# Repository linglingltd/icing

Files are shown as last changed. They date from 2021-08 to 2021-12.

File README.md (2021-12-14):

# Teststandes zur Erzeugung planarer Eisschichten

Eine detailiertere Beschreibung folgt, sobald der Teststand sauber geprüft
und dokumentiert ist.

# Lizenz

Dieses Repository ist Teil des Bachelor-Projekts im Rahmen meines Studiums.
Alle Teile können gemäß CC BY 2.0 verwendet werden.

# Messungsbeginn

Zu Beginn einer Messreihe immer eine Referenzierung des Teststands durchführen!

  * X HOME
  * X 5
  * Y HOME
  * Y 5
  * Z HOME
  * Z 5   (bzw. hoch genug, dass der Sensor nicht mit dem DUT kollidiert)

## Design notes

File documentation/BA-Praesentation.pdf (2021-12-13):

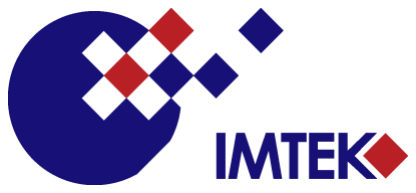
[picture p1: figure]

# Entwurf und Charakterisierung eines kapazitiven Sensors zur Detektion von Eisschichten

Bachelorthesis von Kevin R. Mader 05.11.2021
Institut für Mikrosystemtechnik - IMTEK Albert-Ludwigs-Universität Freiburg

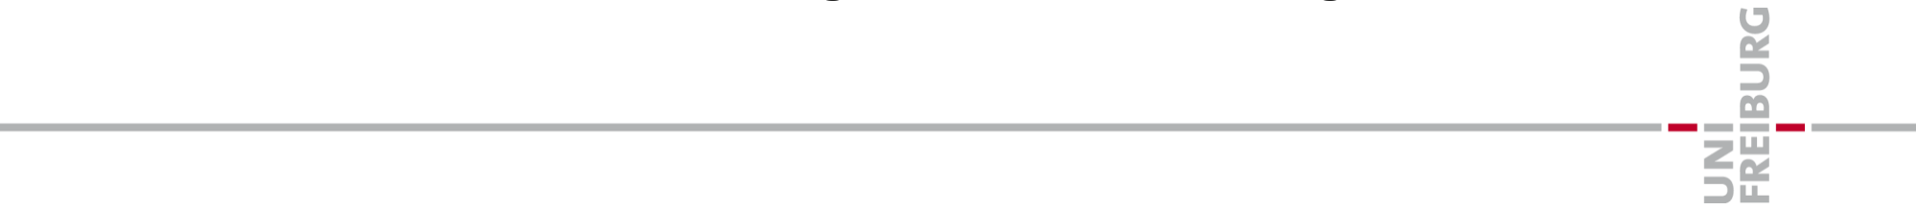
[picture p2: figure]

05.11.2021 | Kevin R. Mader

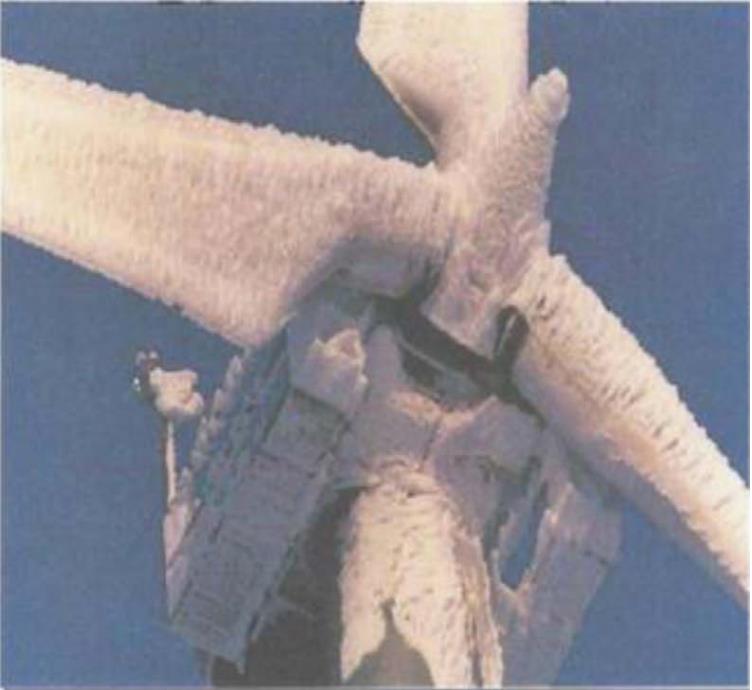
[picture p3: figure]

- 2 -

## Motivation

- Senkung der Effizienz
- Erhöhte mechanische Belastung der Windkraftanlage
- Eiswurf: Gefahr für Mensch, Tier und Gebäude
- Ab kritischer Eisschicht muss die Anlage abgeschaltet werden

(Fakoerde et al)

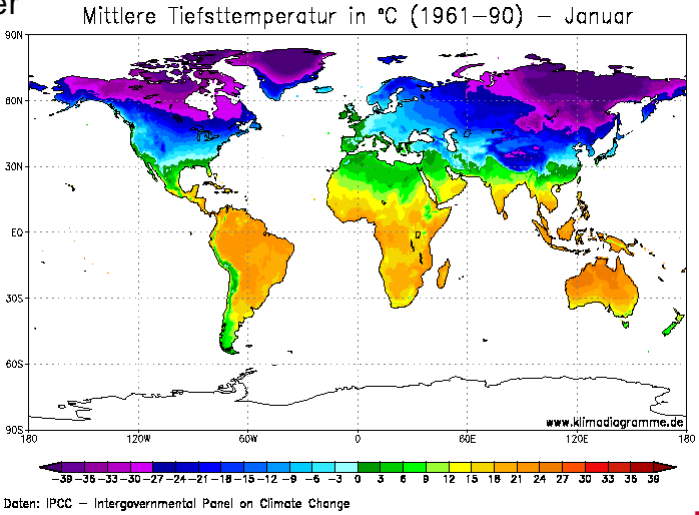
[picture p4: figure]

- 3 -

## Motivation

- Elektrische Energie sollte nah beim Verbraucher generiert werden
- Im Norden starke Winde, aber Vereisungsproblematik
- Vereisung bringt Einbußen der Energiegewinnung von
bis zu 50 % des Jahres-ertrags

## Vereisungsarten

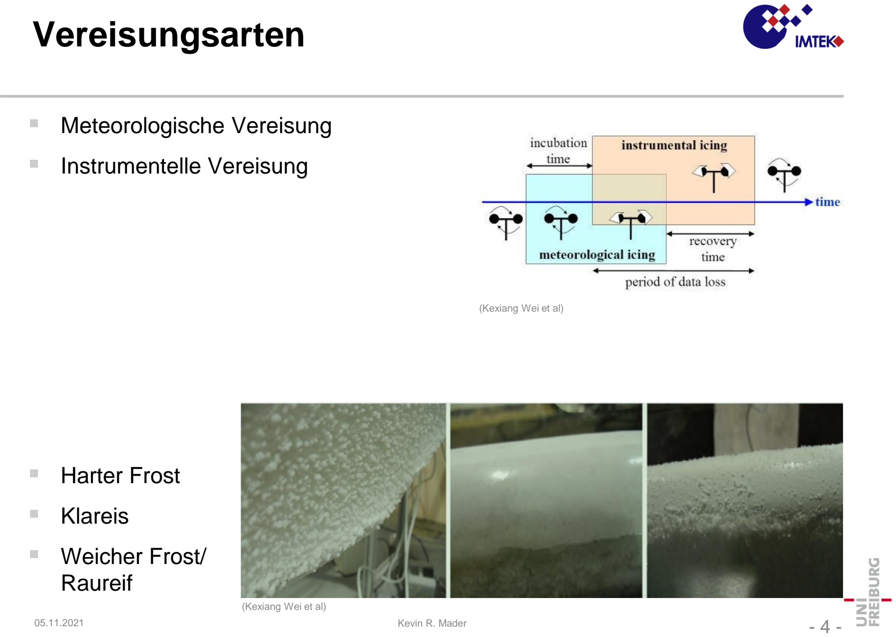
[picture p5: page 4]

- 4 -
- Meteorologische Vereisung
- Instrumentelle Vereisung
- Harter Frost
- Klareis
- Weicher Frost/
Raureif

(Kexiang Wei et al)

(Kexiang Wei et al)

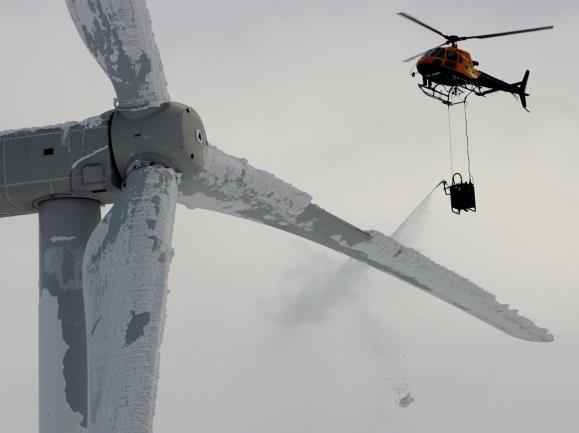
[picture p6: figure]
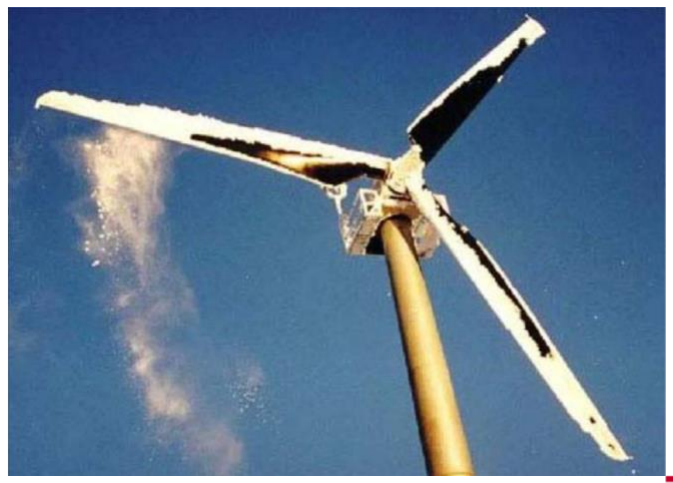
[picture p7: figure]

- 5 -

## Enteisungsmethoden

- Besprühen von Windkraftanlagen mit warmem Wasser
- Beheizen mit Verlustwärme aus der Gondel
- Energieverlust beträgt etwa 120 kW für eine 2.0 MW Windkraftanlage ab 50% Auslastung
- Aktives Beheizen mit Heizelementen
- Schwarze Rotorblätter
- Lotus-Effekt

(Fakoerde et al)

(Energiforsk)

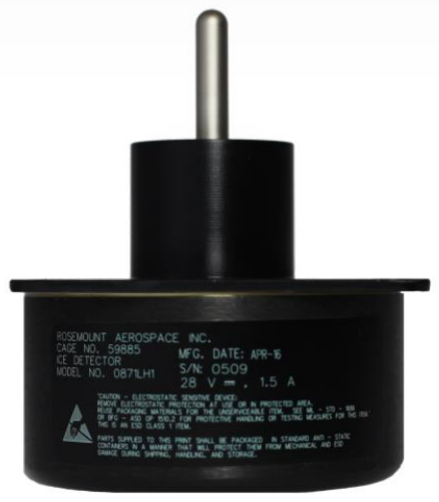
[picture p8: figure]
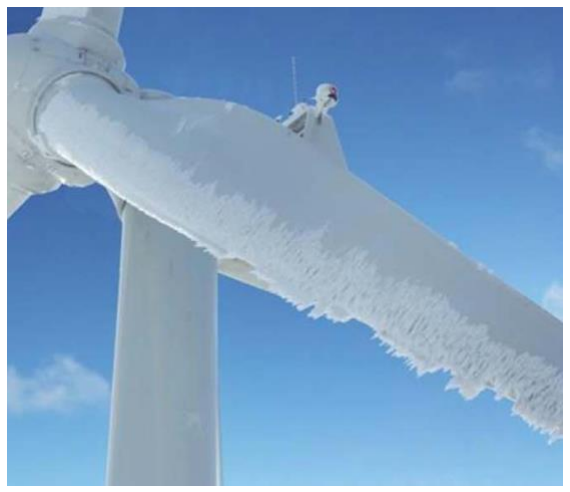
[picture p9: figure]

- 6 -

## Eisdetektion

- Vibrationsanalyse
- Windstärke und Leistungsausgabe
- Kapazitive Detektion
- Auf der Gondel
- Am Rotorblatt

(Fakoerde et al)

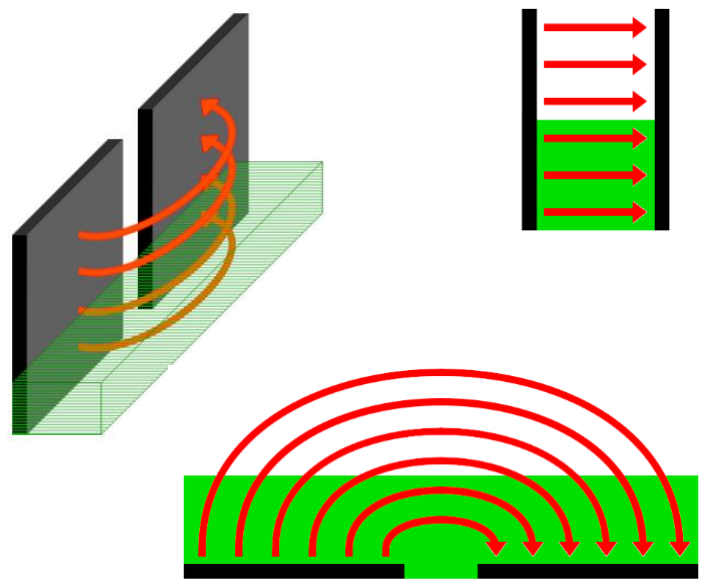
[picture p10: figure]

- 7 -

## Kapazitive Sensoren

- Plattenkondensator:
- Große Fläche b ⋅ t zueinander
- Gerade Feldlinien zwischen den Platten
- Kapazität gegeben durch C =

b⋅t
d

⋅ εr

⋅ ε0

- Lineares Signal über steigenden Füllstand
- Vertikaler koplanarer Kondensator
- Geringe Fläche b ⋅ t
- Überwiegend Streufelder
- Lineares Signal über steigenden Füllstand
- Horizontaler koplanarer Kondensator
- Mit steigendem Füllstand tritt Sättigung ein
Material | Relative Permittivität εr
Vakuum | 1,0
Luft | 1,000576 (0 °C, 105 Pa)
| 1,05404 (0 °C, 107 Pa)
Wasser | 87,9 (0 °C)
| 80,2 (20 °C)
Eis | 100 (– 20 °C, f = 50 Hz)
| 3,2 (– 20 °C, f > 100 kHz)
FR-4 | 3,2 … 4,7

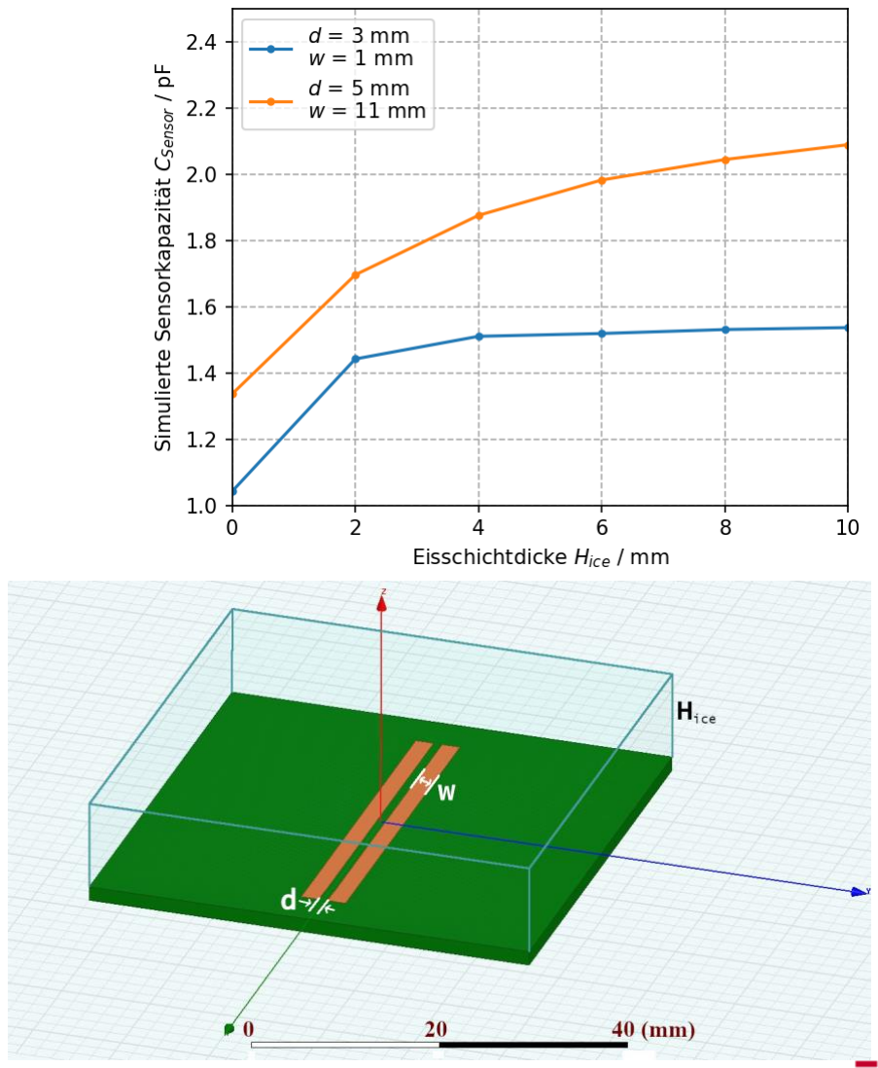
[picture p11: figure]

- 8 -

## Simulation der Sensor-Elektroden

- Simulation mit Leiterbahnbreiten und –
abständen {1 mm, 3 mm, 5 mm, 7 mm, 9 mm, 11 mm}
- Elektroden auf FR-4 (εr = 4,4)
- Umgeben von Vakuum (εr = 1)
- Auftrag mit Eis (εr = 3,2)

## Entworfener Prototyp

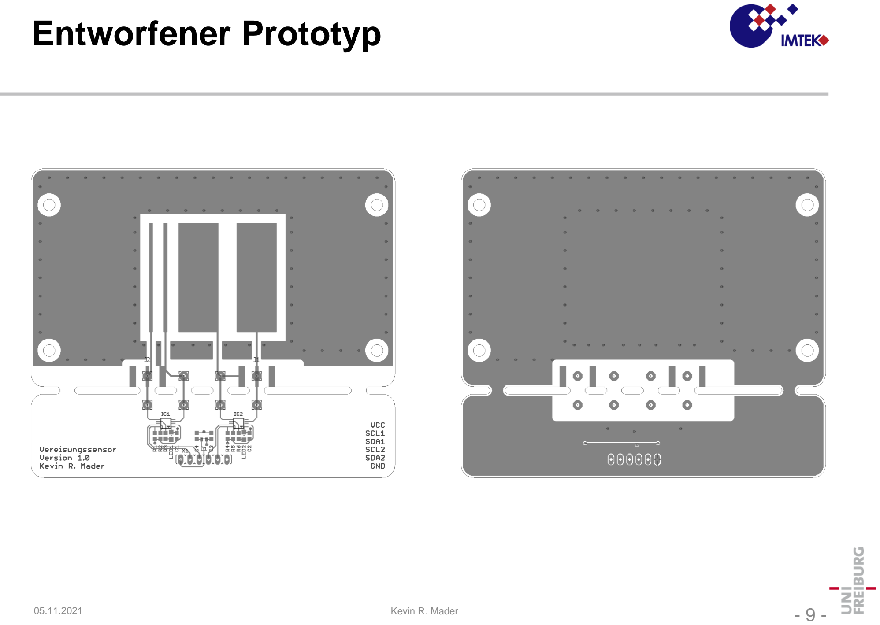
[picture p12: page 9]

- 9 -

## Messaufbau

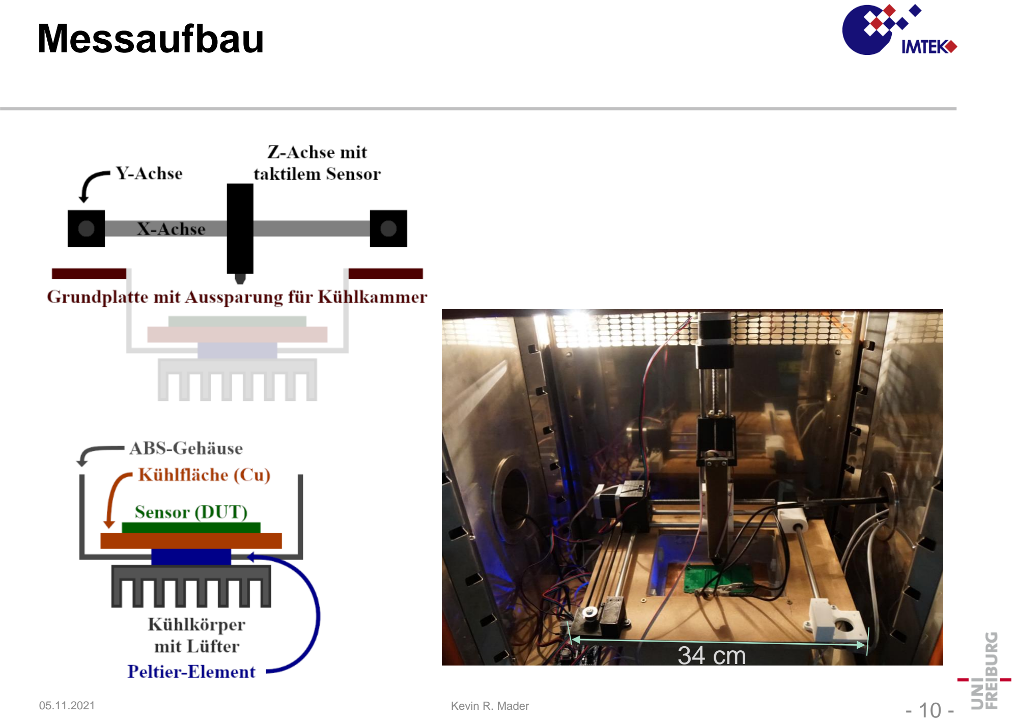
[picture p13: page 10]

- 10 -

34 cm

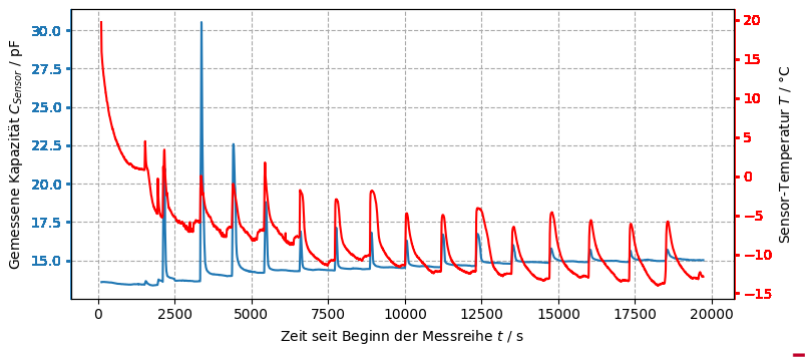
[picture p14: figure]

- 11 -

## Messdurchführung

1. Wasser aufsprühen
2. Einschwingen
3. Höhenvermessung
4. Kapazitätsmessung

- 12 -

## Datenaufzeichnung

Zusammenführen der Messwerte am Computer mit Live-Visualisierung:
- Speicherung:
- Netzwerkanalysator-Messwerte
- Sensortemperatur
- Zeitpunkt in der Messreihe
- Höhenprofile
- Live-Anzeige:
- Durchschn. Sensorkapazität
- Sensortemperatur
- Zeitpunkt in der Messreihe

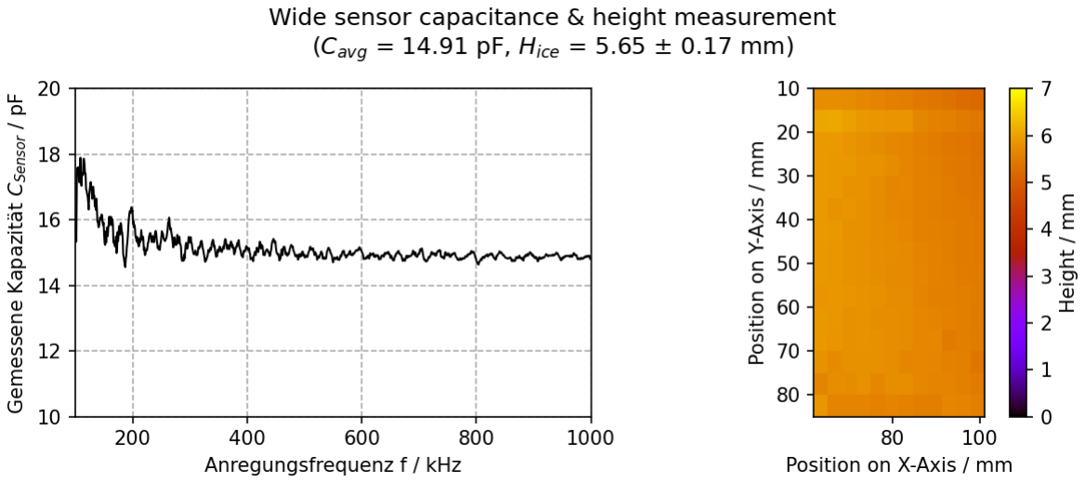
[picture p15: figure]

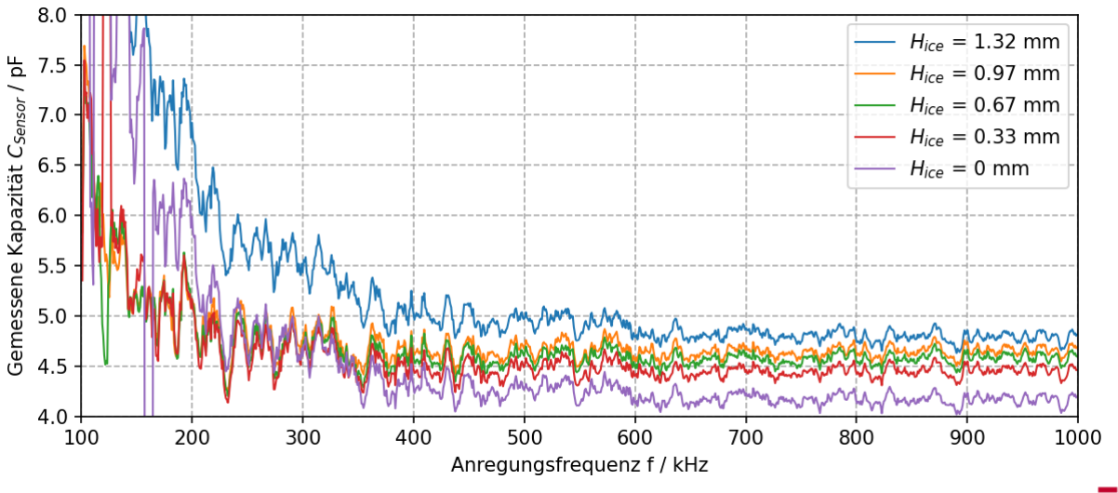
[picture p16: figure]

- 13 -

## Frequenzverhalten des Sensors

- Sinkende Kapazität mit steigender Frequenz
- Stärkeres Rauschen im unteren Frequenzbereich durch Messdauer
- Kapazitätswert aus Mittelwert der Werte zwischen 400 kHz und 1 MHz

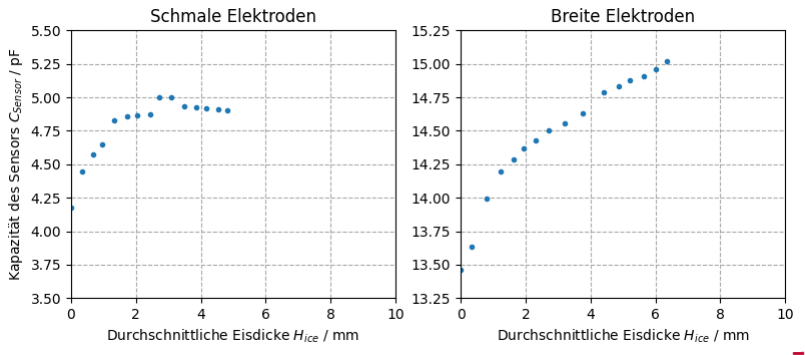
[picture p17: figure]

- 14 -

## Sensorverhalten über Eisschichtdicke

- Erhöhte Grundkapazität durch Anschluss des Netzwerkanalysators
- Schmale Elektrode in Sättigung nach 1 mm Eis

## Vergleich von Messwerten zu Simulation

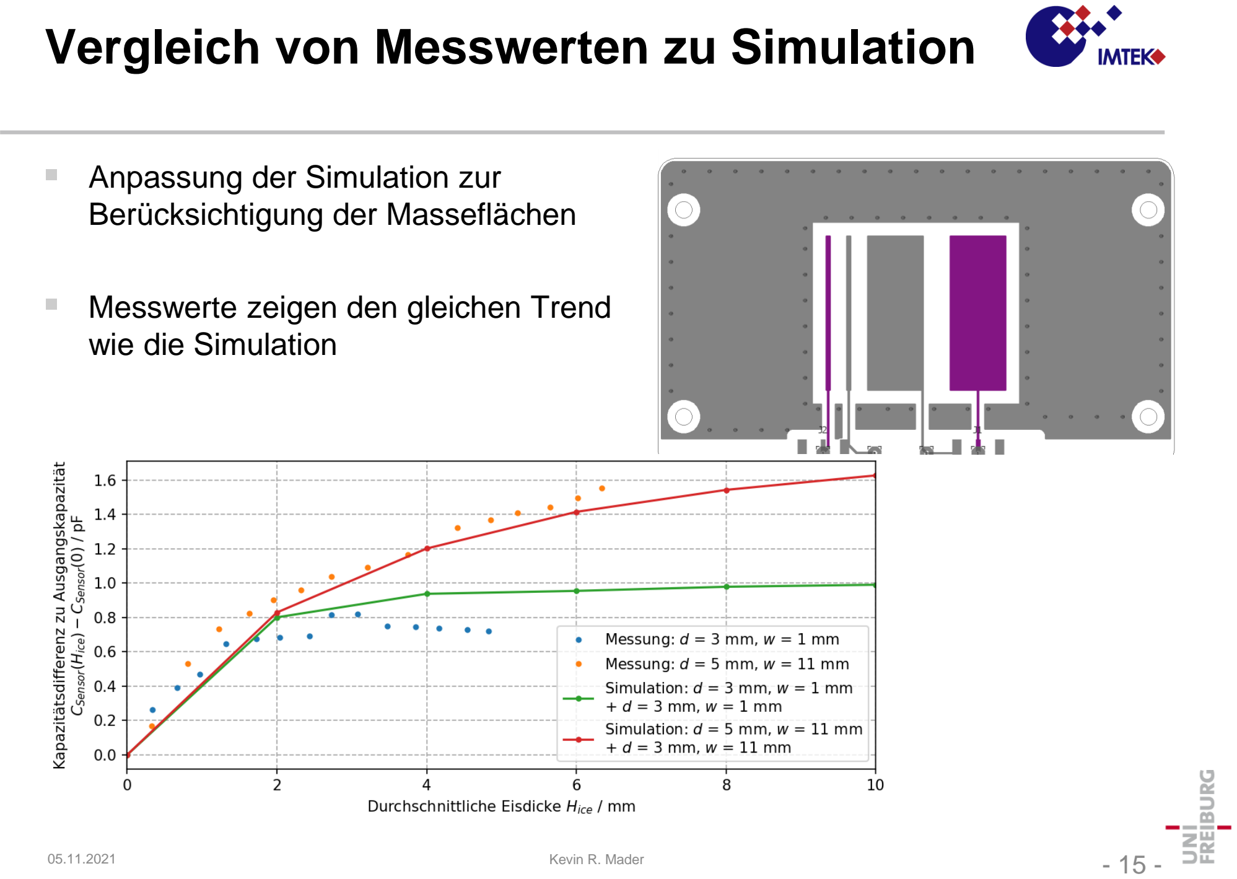
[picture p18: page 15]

- 15 -
- Anpassung der Simulation zur Berücksichtigung der Masseflächen
- Messwerte zeigen den gleichen Trend wie die Simulation

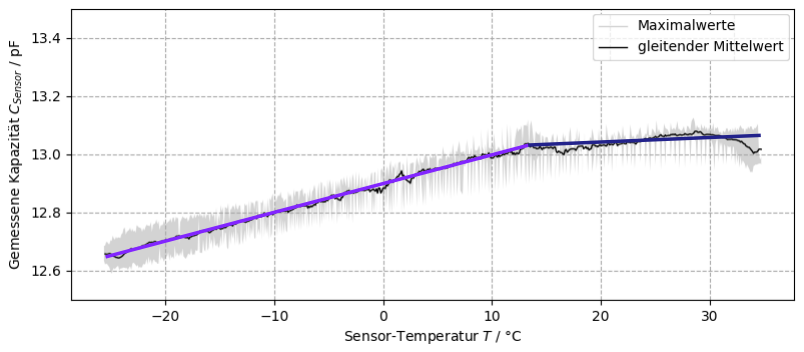
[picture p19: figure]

- 16 -

## Temperaturverhalten des Sensors

- Messung des Sensors im Klimaschrank, Zyklen zwischen −25 °C und +35 °C
- Umgebungstemperatur im Labor θAmbient = 23 °C
- relative Luftfeuchte RH = 50 %
- entspricht RH = 100 % bei θ = 13 °C

- 17 -

## Zusammenfassung

- Die Elektrodenpaare zeigen eine Empfindlichkeit für kleine Eisschichten < 1 mm von

ΔC

ΔHice

= 0.5

pF
mm

für die kleinen Elektroden und ΔC

ΔHice

= 0.7

pF
mm

für
die großen.
- Bei Eisschichten über 2 mm sind die kleinen Elektroden gesättigt, während die großen Elektroden auch hier noch eine Empfindlichkeit um ΔC

ΔHice

= 0.1

pF
mm
zeigen.

- 18 -

## Aussicht

- Messung des Temperaturverhaltens unter kontrollierter Luftfeuchte
- Erweiterung des Teststands um Temperaturregelung
- Detailliertere Charakterisierung des Verhaltens bei Eisbildung und versch. Temperaturen
- Produktion des Sensors auf dünnem, flexiblen Leiterplattenmaterial

- 19 -

## Quellen

- (Fakoerde et al) doi: 10.1016/j.rser.2016.06.080 Ice protection systems for wind turbines in cold climate: characteristics, comparisons and analysis
- (Energiforsk)
Airborne de-icing solutions for wind turbines REPORT 2016:300
- (George Xydis et al) doi: 10.3390/challe6020188
Wind turbine waste heat recovery—A short-term heat loss forecasting approach
- (Kexiang Wei et al) doi: 10.1002/we.2427
A review on ice detection technology and ice elimination technology for wind turbine

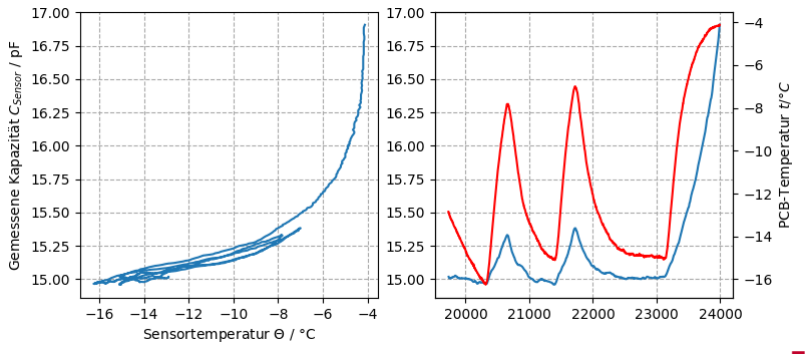
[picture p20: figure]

- 20 -

## Backup #1: Temperaturverhalten mit Eis

- Temperatur erreicht durch Ein- und Auschalten des Peltier-Elements
- Anschmelzen der oberen Eisschicht

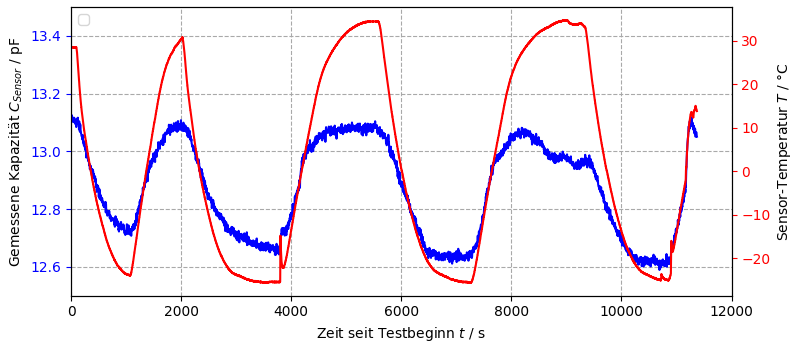
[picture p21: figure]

- 21 -

## Backup #2: Temperaturverhalten ohne Eis

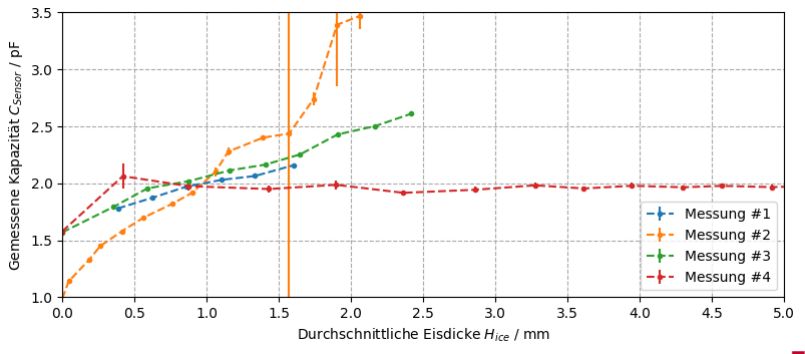
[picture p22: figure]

- 22 -

## Backup #3: LCR-Messungen

- Messung 2: Signifikante Veränderung durch verschieben der Messleitungen
- Messung 1&3: Eisbildung an den Klemmen des LCR-Meters
- Messung 4: Entfernung von Feuchtigkeit und Eis von den Klemmen

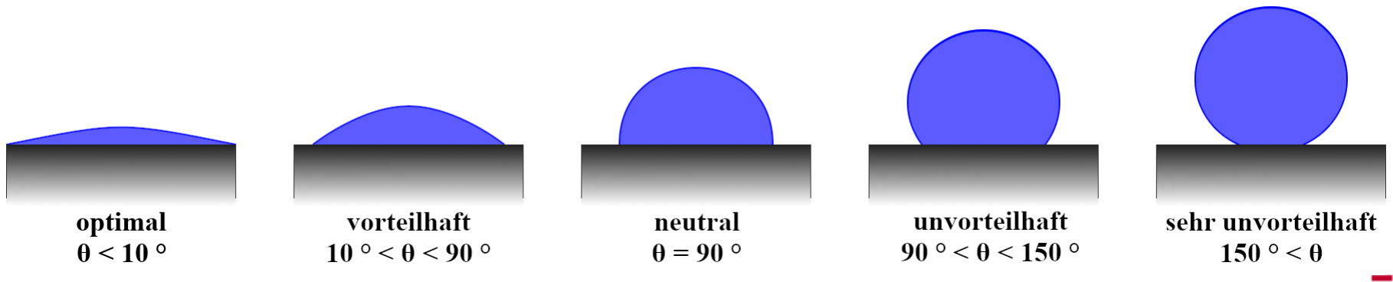
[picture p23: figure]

- 23 -

## Backup #4: Oberflächenenergie

- Der Benetzungswinkel θ
- Oberflächenspannung der Flüssigkeit σL
- der Oberflächenenergie des Körpers σB
- Grenzflächenenergie zwischen den beiden Komponenten σLB
- cos θ =

σB−σLB
σL

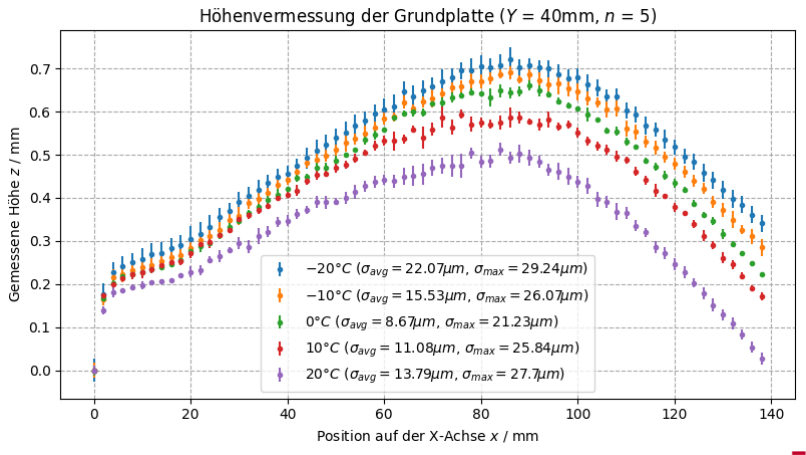
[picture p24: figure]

- 24 -

## Backup #5: Höhenprofildetektion

- Standardabweichung pro Messpunkt: max. 29,24 µm
- Da Temperatur konstantgehalten wird, keine Einflüsse durch Ausdehnung/Kontraktion

- 25 -

## Zeichenfläche

- 26 -

## Mehr Zeichenfläche

- 27 -

## NOCH mehr Zeichenfläche

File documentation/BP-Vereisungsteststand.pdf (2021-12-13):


# Gruppe

2

# Entwicklung und Evaluierung eines

# Teststandes zur Erzeugung planarer

# Eisschichten

# Bachelorprojekt 2021

## Mader, Kevin Rafael, 4732503, mail@kevin-mader.de

Mit Abgabe des Protokolls erklärt die oder der Verfassende, dass sie oder er das Protokoll in Eigenarbeit angefertigt und darin enthaltenes Fremdmaterial entsprechend gekennzeichnet hat. Darüber hinaus sind alle Stellen, die wörtlich oder sinngemäß aus anderen Schriften entnommen wurden, als solche gekennzeichnet. Des Weiteren ist dem Verfasser bekannt, dass eine Zuwiderhandlung als Plagiat gewertet wird und zum Ausschluss aus dem Praktikum führt.

Bachelorprojekt – Entwicklung und Evaluierung eines Teststandes zur Erzeugung planarer Eisschichten

## Inhaltsverzeichnis

## 1 Einleitung

### 1.1 Problemstellung

Zur Charakterisierung von Sensoren müssen bei der Entwicklung Sensormesswerte mit den zu messenden Parametern gegenübergestellt werden können. In der hier geplanten Anwendung soll der Teststand Eisschichten auf einer planaren Oberfläche erzeugen und ein Höhenprofil dieser Schicht ermitteln können, ohne die generierte Schicht bei der Messung zu schädigen.

### 1.2 Theoretischer Hintergrund

1.2.1 Nachbildung der natürlichen Entstehung von Eis

Durch die Kondensation der Luftfeuchtigkeit kann Eis auf kalten Oberflächen entstehen. Um unter Laborbedingungen gezielt hohe Luftfeuchtigkeit zu erreichen wird Luft durch ein Wasserbecken gepumpt. Die Luft nimmt die maximal mögliche Menge an Wasser auf und kann anschließend in einen Testaufbau geleitet werden. Die absolute Wassermenge steigt mit der Temperatur der Luft.

Auch Nebel kann auf kalten Oberflächen Eis bilden, indem die freien Wasserpartikel auf die Oberfläche treffen und gefrieren. Nebel kann durch Ultraschallvernebler im Labor kosteneffizient künstlich erzeugt werden.

Eisbildung durch gefrierenden Regen lässt sich im Labor durch Aufsprühen von Wasser mit Zerstäubern realisieren.

1.2.2 Messung von Schichtdicken

Schichtdicken werden, abhängig von benötigter Auflösung, Messbereich und Material über verschiedene Messmethoden wie Reflexion von Licht oder Schall, mechanische Abtastung, Interferenzmessung oder durch Bestimmung der Resonanz ermittelt.

In diesem Versuch wurde eine mechanische Abtastung gewählt, da ein Messbereich von 10mm erreicht werden soll und Eis Linseneigenschaften aufweist, was eine optische Triangulationsmessung unmöglich macht. Durch das Anbauen einer Tasteinheit an eine Spindel können Distanzen über die Drehung über den Drehwinkel bestimmt werden. In diesem Aufbau wird ein Schrittmotor zur Ansteuerung eingesetzt, wodurch der Drehwinkel über die ausgeführten Schritte des Motors bestimmbar ist.

### 1.3 Konstruktion des Messaufbaus

Der Messaufbau ist dafür vorgesehen in einem Klimaschrank bei einer Umgebungstemperatur von 2°C ≤ θambient ≤ 5°C betrieben zu werden. Hierdurch werden Störungen wie z.B. das Antauen des Eises während einer Abrasterung vermieden.

Der Messaufbau besteht aus den zwei Baugruppen Kühlkammer und Abtastung. Die Kühlkammer wird durch Verspannen in den Messaufbau montiert. Eine Verwendung der Kühlkammer ohne den mechanischen Aufbau der Abtastung oder umgekehrt ist somit problemlos möglich.


Abbildung 1: Kühlkammer des Messaufbaus in Seitenansicht.

Die Kühlkammer, wie in Abbildung 1 dargestellt, besteht aus einer oben offenen Kunststoffbox aus ABS. Innerhalb der Box ist eine Kupferplatte verbaut, welche rückseitig mit einem Peltierelement TEC1-12706 verbunden ist um negative Temperaturen zu erreichen. Die Abwärme wird mittels eines Prozessor-Kühlkörpers des Typs Alpine 11 Plus von Arctic an die Umgebung abgegeben. Um die Rückführung von Wärme vom Kühlkörper zurück in die Kühlkammer möglichst gering zu halten, wurde zusätzliches Isoliermaterial zwischen Kühlkörper und Kupferplatte eingebracht.


Abbildung 2: XYZ-Antrieb zur Abtastung der Oberflächen in der Kühlkammer.

Die Mechanik zur Abtastung von Höhenprofilen ist auf einer 16mm starken MDF-Platten mit einer Breite von 340mm und einer tiefe von 320mm montiert. Für jede der Achsen des Aufbaus wurden zwei

Edelstahlstangen mit 8mm verbaut, auf welchen jeweils zwei Gleitlager des Typs LM8UU laufen, die in die gedruckten Kunststoffteile verpresst wurden.

Der Antrieb der Y-Achse erfolgt über einen GT2-Zahnriehmen um die Bautiefe gering zu halten und dennoch den benötigten Raum der Abtastung zu gewährleisten. Für X- und Z-Achse wurden für höhere Präzision T8-Trapezgewindespindel mit einer Steigung von 2mm verbaut. In den bewegten Kunststoffteilen befinden sich spielfreie Spindelmuttern.

Wie in Abbildung 2 zu erkennen, sind die rechtsseitigen Kunststoffteile der Y-Achse identisch zur linken Seite. Es ist somit Möglich bei Bedarf einen zweiten X-Schlitten im Testaufbau zu verbauen wenn hierfür eine Notwendigkeit besteht.

Alle Kunststoffteile wurden mit einer Schichtdicke von 0.3mm und einer Füllung von 25% mit aktiviertem Support gedruckt. Als Drucker dienten Ultimaker 3 und Ultimaker 2+.

Die Abtastung Erfolgt mit einem Taster des Typs Cherry MX1A-51NN, da dieser gut dokumentiert ist
[1] und eine lineare Betätigungskraft benötigt und keine merkbare Schaltschwelle aufweist, was ruckartige Veränderungen am Eis und Z-Antrieb vermeidet. Als Tastkopf kann eine Spitze aus einem Material mit geringer Wärmekapazität und -leitfähigkeit wie ABS oder PLA eingesetzt werden, um die abgetastete Fläche sauber zu definieren und gleichzeitig einen möglichst geringen Einfluss auf zu messende Eisschichten auszuüben.

Die verwendeten Teile wurden entsprechend der Verfügbarkeit ausgewählt. Eine Anpassung des Aufbaus mit anderen Materialien ähnlicher Eigenschaften ist möglich, jedoch muss jeder Nachbau neu charakterisiert werden. Größenbeschränkungen des Aufbaus sind gegeben durch die verwendete Klimakammer VCL4010 der Firma Vötsch.

Die konstruierten Kunststoffteile des Aufbaus sowie Firmware und die verwendeten Python-Programme zur Datenauswertung sind im Repository zu diesem Projekt [2] frei zugänglich.

### 1.4 Steuerung des Messaufbaus

Um den Messaufbau simpel zu halten, wird im Messaufbau die serielle Schnittstelle des Arduino Mega zur Übertragung von Steuerbefehlen und Messwerten verwendet.

Befehle für den Messaufbau sind im ASCII-Format mit beendendem Zeilenumbruch \n codiert. Tabelle 1 zeigt alle verfügbaren Befehle zur Steuerung der einzelnen Achsen mit N ∈ {X, Y, Z}. Angegebene Fahrdistanzen sind Beispiele und beziehen sich immer auf den Abstand zum Endstop.

Tabelle 1: Achsenspezifische Steuerbefehle des Aufbaus.

Befehl | Funktion
N HOME | Home Achse N
N 10 | Absolutes Verfahren der Achse auf Position 10mm
N +10 | Relatives Verfahren der Achse um 10mm
N -10 | Relatives Verfahren der Achse um -10mm
N +10s | Relatives Verfahren der Achse um 10 Schritte
N -10s | Relatives Verfahren der Achse um -10 Schritte

Befehle zum automatischen Durchführen von Messungen werden während der Verwendung des Messstandes hinzugefügt und sind momentan nicht implementiert.

### 1.5 Charakterisierung

1.5.1 Erzeugung von Eisschichten

Zur Erzeugung von Eisschichten wurden drei Ansätze verfolgt: Einführen hoher Luftfeuchtigkeit, Vernebeln von Wasser innerhalb der Kammer sowie direktes aufsprühen von Wasser auf den Sensor.


Abbildung 3: Generierte Eisstrukturen durch Zufuhr von Luft mit hoher Luftfeuchtigkeit.

Durch Einleitung von Luft in die Testkammer über ein Wasserbad wurde die zugeführte Luft mit einer Temperatur θluft = 23°C mit Feuchtigkeit angereichert. Die Luftfeuchtigkeit gefriert beim passieren der Sensorfläche und bildet Kristallstrukturen auf der Oberfläche, wie in Abbildung 3 zu erkennen.


Abbildung 4: Erzeugte Eisschicht durch Einbringen eines Ultraschallverneblers in die Kühlkammer.

Vernebeln von Wasser mittels Ultraschallverneblern sorgt für eine hohe Konzentration freier Wassertröpfchen in der Kühlkammer, welche sich analog zur hohen Luftfeuchtigkeit zu Kristallstrukturen auf der Sensoroberfläche verbinden.

Abbildung 5: Durch Aufsprühen von Wasser generierte Eisflächen.

Direktes Aufsprühen von Wasser auf eine Sensorfläche erzeugt größere Eisflächen, wie Abbildung 5 darstellt. Das Eis ist nicht homogen, sondern bildet kleinere Inseln auf dem Sensor.


Abbildung 6: Homogene Eisschicht durch eine Kombination aus Vernebeln und Besprühen.

Abbildung 6 zeigt eine homogene Eisschicht, die durch benebeln der Platine mit Wasser und anschließendes Besprühen erzeugt wurde. Die Benetzung der Fläche ist gleichmäßig und es sind mit bloßem Auge keine Unreinheiten im inneren des Eises erkennbar.

1.5.2 Messbereich und vertikale Auflösung

Der Messaufbau wird angetrieben über NEMA 17-Motoren mit einem Schrittwinkel von 1.8°, angesteuert durch einen DRV8825 im 1/32 Microstepping. Unter Betrachtung der verbauten T8-Trapezgewindespindel mit 2mm Steigung ergibt sich somit eine minimale Auflösung der Z-Achse von

Δℎmin = 2mm ⋅

360°
1,8° ⋅

1
32 = 312,5nm

Gegeben durch die Konstruktion ist die messbare Grundfläche 150x80mm bei einer maximalen Höhe von 40mm über der Grundplatte.

1.5.3 Reproduzierbarkeit

Zur Messung der Reproduzierbarkeit fährt der Aufbau mehrfach das gleiche Muster ab und nimmt bei jedem Durchlauf 60 Messungen der Grundplatte an verschiedenen Punkten auf. Hierbei wird einmalig vor Beginn der Messung ein Punkt auf der Trägerplatte als 0 referenziert und anschließend der Tast-Kopf auf eine Höhe von ℎStart = 6mm (19.200 Scℎritte) über der Messfläche gefahren. Für die Messung wird der Tast-Kopf abgesenkt, bis der Taster ein Signal durch Berühren der Grundfläche gibt. Die Differenz der Schritte zum referenzierten Punkt ergibt somit die Höhendifferenz anhand der in 1.5.1 berechneten Auflösung.

Abbildung 7 zeigt die aufgezeichneten Messpunkte mit zugehöriger Standardabweichung über die X-Achse bei einer Y-Achsen Position pY = 50mm.


Abbildung 7: Messung der Reproduzierbarkeit ohne Homing der Z-Achse.

Um zu überprüfen ob bei Messungen Schritte verloren werden, werden die Messpunkte in Abbildung 8 in Relation gemäß Formel (1) zur vorherigen Messung an der gleichen Position dargestellt:

δn = ℎMPx,n − ℎMPx,n−1. | (1)

Es wurden je 10 Messungen an 60 Messpunkten aufgenommen. Entsprechend zeigt die Darstellung das δn für 540 Messungen.


Abbildung 8: Abweichung der Messwerte zum vorherigen Wert an selbiger Position ohne Homing.

Durch regelmäßiges Homing der Z-Achse ist es möglich Langzeitdrifts entgegen zu wirken, indem Veränderungen durch verlorene Schritte aus vorangegangenen Messungen oder eine Verformung des Messaufbaus ausgeglichen werden. Ergebnisse mit einem Homing vor jedem Durchlauf sind in Abbildung 9 und Abbildung 10 analog dargestellt.


Abbildung 9: Messung der Reproduzierbarkeit mit Homing der Z-Achse nach jedem Durchlauf.


Abbildung 10: Abweichung der Messwerte zum vorherigen Wert an selbiger Position mit Homing.

1.5.4 Differenzelle Höhenmessung

Die Höhe von aufgetragenem Eis wird differenziell bestimmt. Hierzu wird die Höhe der Grundplatte Hbase initial vermessen. Nach dem Auftrag von Eis oder anderen zu bestimmenden Schichten wird eine weitere Höhenvermessung Hice durchgeführt. Durch Subtraktion der Messergebnisse nach Formel (2) kann die Höhe des Auftrags Hδ bestimmt werden:

Hδ = Hice − Hbase. | (2)

Um eine definierte Höhe vermessen zu können, wurde Kapton-Band des Typs 1205 von 3M auf die Grundplatte aufgeklebt. Dieses weist eine Höhe von ℎKapton = 3mil = 0,076mm auf [2] und stellt somit eine der feinsten zu messenden Strukturen dar.


Abbildung 11: Differenzielle Höhenmessung von drei Kapton-Bändern auf der Grundplatte.

### 1.6 Datengenerierung / Visualisierung

Die Messwerte des Systems werden seriell ausgegeben und können direkt in eine Textdatei kopiert werden. Die Messwerte einer Messreihe sind hierbei separiert durch Tabulatoren und eine Zeile spiegelt eine komplette Messreihe wider. Beigefügte Python-Programme [1] übernehmen das Visualisieren der Daten nach Bedarf, wie Abbildung 12 zu entnehmen ist.


Abbildung 12: Beispielhafte Heatmap-Darstellung der Höhenvermessung der Grundfläche.

### 1.7 Optionen der Erweiterung

Durch das verbauten eines zweiten X-Schlittens kann beispielsweise ein Sprühkopf oder eine andere Erweiterung im Messaufbau eingeführt werden. Die Konstruktion sieht diese bereits vor, jedoch würde sich hierbei der Verfahrbereich um 50mm verringern. Durch Verlängerung der Y-Achse wird dieses Problem umgangen.

Bei größeren Testaufbauten ist die Belastung der Führungsstangen zu beachten und diese ggf. durch Größere zu ersetzen. Ebenso könnten die Kunststoffteile für größere Konstruktionen ungeeignet sein.

Die Verwendung von Open-Loop Schrittmotoren ist in dieser Anwendung ausreichend, jedoch könnte für höhere Genauigkeit und bessere Reproduzierbarkeit besonders bei der Z-Achse ein Closed-Loop Schrittmotor eingesetzt werden.

Optional ist es auch möglich, an den Unterseiten des X-Y-Antrieb Abdeckungen zu befestigen, sodass die Testkammer möglichst gut verschlossen ist um Störeinflüsse von außen auf den Prüfling zu reduzieren.

## 2 Diskussion

Die generierten Eisstrukturen zeigen, dass durch eine Kombination von benebeln und besprühen die für unsere Anwendung besten Ergebnisse liefern. Das zuführen von Luft mit hoher Luftfeuchte bildet kleine Kristalle, jedoch ist deutlich das Muster der Luftverwirbelung zu erkennen. Durch den Einsatz eines Strömungsgleichrichter und gezieltem einseitigen Zuführen der Luft mit Auslass auf der gegenüberliegen Seite könnte dieses Problem reduziert werde.

Vernebeln von Wasser innerhalb der Kühlkammer sorgte für ähnliche Eisstrukturen wie die hohe Luftfeuchtigkeit, jedoch deutlich homogener außer am Auslass des Neblers, der sich zur Laufzeit des Tests neben dem Temperaturfühler befand.

Aufsprühen erzeugt solide Eisschichten, jedoch erfolgt keine gleichmäßige Benetzung der Sensorfläche. Dies ist auf die Oberflächenenergie des Lötstoplacks der Platine zurückzuführen, wodurch das Wasser vor dem Gefrieren nur zu einer mittelmäßigen Benetzung kommt.

Wird die Platine erst mit einem Nebler vollflächig mit Eiskristallen übersät, so bildet sich beim Aufsprühen wie Abbildung 6 zu sehen eine homogene Eisschicht, da die Eiskristalle des Nebels die Oberfläche des Sensors vergrößern und somit die Benetzung fördern. Für die Eisschicht wurde kein Höhenprofil aufgenommen, da der Versuch auf die Machbarkeit der Eis-Generierung abzielte und nicht auf die genauere Vermessung selbiger.

Die Höhenvermessung mit dem Aufbau funktioniert reproduzierbar. Die Krümmung der Messung ist durch die Krümmung der Kupferplatte durch verschrauben über einem Peltier-Element erklärbar. Wird kein regelmäßiges Homing durchgeführt ist zu erkennen, dass über die Länge des Versuchs zunehmend Schritte des Motors verloren werden. Da im Aufbau nur Open-Loop-Motoren eingesetzt werden ist dieses Verhalten erwartbar. Eine Verringerung der verlorenen Schritte wäre durch eine Reduktion der Geschwindigkeit, Erhöhung des Motorenstroms oder langsamerem Anlauf und Stop der Motoren möglicherweise erreichbar.

Wird die Höhenmessung vor jedem Durchlauf referenziert, so gibt es eine generelle Verschiebung der Messreihe durch eine Verschiebung des Nullpunktes, jedoch werden hierbei Langzeiteffekte reduziert und die durchschnittliche Standardabweichung von δno ℎoming = 13,52 µm auf δno ℎoming = 8,22 µm reduziert.

Abweichungen in den Höhenprofilen in Abbildung 7 zu Abbildung 9 sind durch leichten Versatz an der Y-Position zu erklären, da sich in diesen Messreihen der Riemenantrieb der Y-Achse etwas gelockert hatte.

Die Differenzielle Höhenmessung mit Kapton-Band zeigt, dass die Messwerte im Rahmen der Erwartung liegen. Da die Abweichungen der Messungen reproduzierbar sind, kann diese möglicherweise auf eine Verunreinigung der Kupferplatte beim Auftragen der Kapton-Streifen zurückzuführen sein. Weitere Messungen zur Ursachenbestimmung hierzu sollten in einer nachfolgenden Messreihe durchgeführt werden.

## 3 Zusammenfassung

Mit dem entwickelten Teststand können Eisschichten in verschiedenen Methoden generiert und vermessen werden. Die verschiedenen Möglichkeiten der Generierung von Eis stellen verschiedene reale Vorkommen von Eis dar und ermöglichen so eine weitreichende Charakterisierung von Sensoren.

Die Höhenprofilmessung des Messaufbaus ist reproduzierbar und die Messwerte der Höhe wirken valide. Die erzielte Auflösung und die erhaltenen Messwerte lassen erwarten, dass der Messstand für die geplante Anwendung geeignet ist.

## 4 Literaturverzeichnis

[1] „Cherry | MX | Produktinformation,“ | Cherry | MX, | [Online]. | Available:
https://www.cherrymx.de/en/mx-original/mx-speed-silver.html#techSpecs. [Zugriff am 13 08 2021].
[2] K. Mader, „Projekt GitHub-Repository,“ Albert-Ludwigs-Universität Freiburg, 2021. [Online]. Available: https://github.com/linglingltd/icing. [Zugriff am 12 08 2021].
[3] 3M, | „Electrical | Tape | 1205 | Datasheet,“ | 2017. | [Online]. | Available:
https://www.mouser.de/datasheet/2/1/78-8124-4706-4%20Rev%20D-38225.pdf. [Zugriff am 12 08 2021].

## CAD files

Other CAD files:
mechanical/X-Carriage.f3d
mechanical/X-End.f3d
mechanical/X-Idler.f3d
mechanical/Y-Belt-Clamp.f3d
mechanical/Y-Idler.f3d
mechanical/Y-Motor.f3d
mechanical/Z-Carriage.f3d
mechanical/Z-Holder.f3d
mechanical/Z-Motor.f3d

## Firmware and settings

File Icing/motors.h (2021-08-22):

#ifndef MOTORS_H
#define MOTORS_H


#define A0   (54)
#define A1   (55)
#define A2   (56)
#define A3   (57)
#define A4   (58)
#define A5   (59)
#define A6   (60)
#define A7   (61)
#define A8   (62)
#define A9   (63)
#define A10  (64)
#define A11  (65)
#define A12  (66)
#define A13  (67)
#define A14  (68)
#define A15  (69)

#define XSTEP    A0
#define XMIN     3
#define XMAX     2
#define XEN      38
#define XDIR     A1

#define YSTEP    A6
#define YMIN     14
#define YMAX     15
#define YEN      A2
#define YDIR     A7

#define ZSTEP    46
#define ZMIN     18
#define ZMAX     19
#define ZEN      A8
#define ZDIR     48

#define E0STEP   26
#define E0EN     24
#define E0DIR    28

#define E1STEP   36
#define E1EN     30
#define E1DIR    34

#define X_STEPS_PER_MM  3200
#define Y_STEPS_PER_MM  164
#define Z_STEPS_PER_MM  3200

const uint32_t stepsPerMm[3] = { X_STEPS_PER_MM, Y_STEPS_PER_MM, Z_STEPS_PER_MM };

void initMotors(void);

void enableMotor(char id);
void disableMotors(void);
void disableMotor(char id);

void homeMotors();
uint32_t homeMotor(char id, uint16_t dly);

void moveMotor(char id, uint8_t dir, uint32_t steps, uint16_t dly);
void moveMotorAbsolute(char id, uint32_t pos, uint16_t dly);

#endif

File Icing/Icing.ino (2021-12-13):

#include "./motors.h"
#define LED       13

#define FAN       9
#define PELTIER   8

#define ORN   A12
#define YLO   44
#define PNK   A10
#define BLU   A5

// X 55 - X 100
// Y 10 - Y 45
/* Controlling via Serial:
 *  
 *  N = Axis in {X, Y, Z}
 *  N HOME    Homing Axis N
 *  N 10      Moving Axis to 10mm absolute
 *  N +10      Moving Axis by +10mm
 *  N -10      Moving Axis to -10mm
 *  N s10      Moving Axis to 10 Steps absolute
 *  N +s10      Moving Axis by +10 Steps
 *  N -s10      Moving Axis to -10 Steps
 */

void printHeading(void);

void setup() {
  Serial.begin(115200);
  // put your setup code here, to run once:
  pinMode(LED, OUTPUT);
  pinMode(PELTIER, OUTPUT);
  pinMode(FAN, OUTPUT);

  pinMode(19, INPUT_PULLUP);

  initMotors();
  disableMotors();

  digitalWrite(FAN, HIGH);
  //digitalWrite(PELTIER, HIGH);

  
  Serial.print("\n");
  Serial.print("\n");
  Serial.print("\n"); 
  for(uint8_t i=0;i<62;i++) {
    Serial.print(i);
    Serial.print("\t");
  }
  Serial.print("\n");

  /*homeMotor('X', 10);
  moveMotor('X', 0, 10*200*16, 10);
  homeMotor('X', 25);
  moveMotor('X', 0, 5*200*32, 10);
  //disableMotors();
  homeMotor('Z', 10);
  moveMotor('Z', 0, 100*16, 90);
  homeMotor('Z', 450);
  moveMotor('Z', 0, 3*200*32, 90);

  //Put Y in correct position manually!
  delay(5000);
  moveMotor('Y', 1, 1, 100);*/
}

#define DELAYTIME 900
uint16_t steps = 0, i = 300;

uint8_t j = 0;

void loop() {
  while(Serial.available()) {
    handleSerial();
  }
  if(j == 1) {
    j = 0;
    uint32_t steps;
    homeMotor('X', 10);
    moveMotor('X', 0, 200*16, 10);
    homeMotor('X', 50);
    for(uint8_t i=0;i<60;i++) {
      steps = homeMotor('Z', 50);
      moveMotor('Z', 0, steps, 50);
      Serial.print((int32_t)steps-(3*200*32));
      Serial.print("\t");
      moveMotor('X', 0, 200*32, 25);
    }
    Serial.print("\n");
  } else if(j == 2) {
    j = 0;
    uint32_t steps;
    homeMotor('X', 10);
    moveMotor('X', 0, 10*200*16, 10);
    homeMotor('X', 25);
    moveMotor('X', 0, 5*200*32, 10);
    homeMotor('Z', 10);
    moveMotor('Z', 0, 100*16, 90);
    homeMotor('Z', 450);
    moveMotor('Z', 0, 2*200*32, 90);
    homeMotor('X', 25);
    for(uint8_t i=0;i<62;i++) {
      executeZscan();
      moveMotor('X', 0, 200*32, 25);
    }
    Serial.print("\n");
  } else {
    //disableMotors();
  }
  delay(100);
}

void printHeading(void) {
  // This function is obsolete, could be scrapped.
  for(uint8_t i=0;i<62;i++) {
    Serial.print(i);
    Serial.print("\t");
  }
  Serial.print("\n");
}

char rcvc = 0, rcv[20] = {0};
uint8_t rcvct = 0;
void handleSerial(void) {
  char axis = '0';
  rcvc = Serial.read();
  if(rcvc == '\n') {
    Serial.print(rcv);
    Serial.print(": ");
    if(0 == strncmp(rcv, "X ", 2)) axis = 'X';
    else if(0 == strncmp(rcv, "Y ", 2)) axis = 'Y';
    else if(0 == strncmp(rcv, "Z ", 2)) axis = 'Z';

    // Controlling individual Axis
    if(axis != '0') {
      
      if(0 == strncmp(rcv+2, "HOME", 4)) {  // Homing
        homeMotor(axis, (axis == 'Y') ? 100 : 25);
        Serial.print("Homed.\n");
      } else if(rcv[2] == '-' || rcv[2] == '+') {  // Relative Bewegung
        uint32_t stp = (rcv[3] == 's') ? strToInt(rcv+4) : strToInt(rcv+3);
        moveMotor(axis, 
            (rcv[2] == '-') ? 1 : 0,
            stp * ((rcv[3] == 's') ? 1 : stepsPerMm[axis-'X']),
            (axis == 'Y') ? 100 : 25);
        Serial.print("Moved relative.\n");
      } else {  // Absolte Bewegung
        uint32_t stp = (rcv[2] == 's') ? strToInt(rcv+3) : strToInt(rcv+2);
        moveMotorAbsolute(axis, 
            stp * ((rcv[2] == 's') ? 1 : stepsPerMm[axis-'X']), 
            (axis == 'Y') ? 100 : 25);
        Serial.print("Moved absolute.\n");
      }
    } else if(0 == strcmp(rcv, "SCAN")) {
      Serial.print("Exec. area scan.\n");
      areaScan((uint32_t)3200*55, (uint32_t)164*10, (uint32_t)3200, (uint32_t)164, 45, 30);
    } else if(0 == strcmp(rcv, "FASTSCAN")) {
      Serial.print("Exec. area scan.\n");
      areaScan((uint32_t)3200*55, (uint32_t)164*10, (uint32_t)3200*5, (uint32_t)164*5, 10, 8);
      Serial.print("\n\n");
    } else if(0 == strcmp(rcv, "FASTSCANL")) {
      Serial.print("Exec. area scan.\n");
      areaScan((uint32_t)3200*57, (uint32_t)164*10, (uint32_t)3200, (uint32_t)82*5, 10, 15);
      Serial.print("\n\n");
    } else if(0 == strcmp(rcv, "FASTSCANR")) {
      Serial.print("Exec. area scan.\n");
      areaScan((uint32_t)3200*+62, (uint32_t)164*10, (uint32_t)3200*3, (uint32_t)82*5, 13, 15);
      Serial.print("\n\n");
    } else if(0 == strcmp(rcv, "P=1")) {
      digitalWrite(PELTIER, HIGH);
      Serial.print("P set to 1\n");
    } else if(0 == strcmp(rcv, "P=0")) {
      digitalWrite(PELTIER, LOW);
      Serial.print("P set to 0\n");
    } else if(0 == strcmp(rcv, "X-Sweep")) {
      j = 1;
      Serial.print("Starting X-Sweep\n");
    } else if(0 == strcmp(rcv, "X-Sweep2")) {
      j = 2;
      Serial.print("Starting X-Sweep2\n");
    } else {
      // Nope
    }
    
    while(rcvct > 0) {
      rcv[rcvct-1] = 0; 
      rcvct--;
    }
  }
  else if(rcvct < 19) {
    rcv[rcvct] = rcvc;
    rcvct++;
  }
}

uint32_t strToInt(char *txt) {
  uint32_t ret = 0;
  while(*txt) {
    if(*txt >= '0' && *txt <= '9') {
      ret *= 10;
      ret += *txt - '0';
      txt++;
    } else {
      break;
    }
  }
  Serial.print(ret);
  return ret;
}

void areaScan(uint32_t ax, uint32_t ay, uint32_t stepx, uint32_t stepy, uint8_t nx, uint8_t ny) {
  // @@@ Probably do some Z-Homing before running
  
  // Goto start
  moveMotorAbsolute('X', ax, 25);
  moveMotorAbsolute('Y', ay, 25);

  // Start scanning
  for(uint8_t y=0; y<ny; y++) {
    if(y != 0) {
      moveMotor('Y', 0, stepy, 100);
      moveMotorAbsolute('X', ax, 25); // Do this last due to wobble on y.
    }
    for(uint8_t x=0; x<nx; x++) {
      if(x != 0) moveMotor('X', 0, stepx, 25);
      executeZscan();
    } 
  }
  
  moveMotorAbsolute('X', 10*X_STEPS_PER_MM, 25);
  moveMotorAbsolute('Y', 10*Y_STEPS_PER_MM, 25);
}

void executeZscan() {
  steps = homeMotor('Z', 50);
  moveMotor('Z', 0, steps, 50);
  Serial.print((int32_t)steps-(2*200*32));
  Serial.print("\t");
}

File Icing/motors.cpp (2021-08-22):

#include <Arduino.h>
#include "./motors.h"

const uint32_t motorMax[3] = { (uint32_t)3200*140, (uint32_t)164*100, (uint32_t)3200*70 };
uint32_t motorPos[3];
uint8_t initialized = 0;
uint8_t homed;

void initMotors(void) {
  pinMode(XMIN, INPUT_PULLUP);
  pinMode(XMAX, INPUT_PULLUP);
  pinMode(XSTEP, OUTPUT);
  pinMode(XEN, OUTPUT);
  pinMode(XDIR, OUTPUT);
  digitalWrite(XEN, HIGH);
  
  pinMode(YMIN, INPUT_PULLUP);
  pinMode(YMAX, INPUT_PULLUP);
  pinMode(YSTEP, OUTPUT);
  pinMode(YEN, OUTPUT);
  pinMode(YDIR, OUTPUT);
  digitalWrite(YEN, HIGH);
  
  pinMode(ZMIN, INPUT_PULLUP);
  pinMode(ZMAX, INPUT_PULLUP);
  pinMode(ZSTEP, OUTPUT);
  pinMode(ZEN, OUTPUT);
  pinMode(ZDIR, OUTPUT);
  digitalWrite(ZEN, HIGH);
  homed = 0;
}

void enableMotor(char id) {
  int pin;
  switch(id) {
    case 'X': 
      pin = XEN;
      break;
    case 'Y':
      pin = YEN;
      break;
    case 'Z':
      pin = ZEN;
      break;
    default:
      return;
  }
  digitalWrite(pin, LOW);
}

void disableMotors(void) {
  disableMotor('X');
  disableMotor('Y');
  disableMotor('Z');
}

void disableMotor(char id) {
  int pin;
  switch(id) {
    case 'X': 
      pin = XEN;
      homed &= ~0x01;
      break;
    case 'Y':
      pin = YEN;
      homed &= ~0x02;
      break;
    case 'Z':
      pin = ZEN;
      homed &= ~0x04;
      break;
    default:
      return;
  }
  digitalWrite(pin, HIGH);
}


void moveMotorAbsolute(char id, uint32_t pos, uint16_t dly) {
  uint32_t currPos = motorPos[id - 'X'];
  
  // Never exceed Axis-Maximum
  if(pos > motorMax[id - 'X']) return;

  // Move motor accordingly
  if(currPos < pos) {
    return moveMotor(id, 0, pos-currPos, dly);
  } else if(currPos > pos) {
    return moveMotor(id, 1, currPos-pos, dly);
  }
}

void moveMotor(char id, uint8_t dir, uint32_t steps, uint16_t dly) {
  int pinStep, pinDir;
  // Home, if Axis has not been homed.
  /*Serial.print(id);
  Serial.print(" is at ");
  Serial.print(motorPos[id - 'X']);
  Serial.print(" should move by ");
  Serial.print(steps);
  Serial.print('\n');*/
  
  if((homed & (0x01 << (id - 'X'))) != (0x01 << (id - 'X'))) {
    homeMotor(id, dly);
  }

  // Check if movement is acceptable
  if(dir == 1 && steps > motorPos[id - 'X']) {
    return;
  } else if(dir == 0 && steps+motorPos[id - 'X'] > motorMax[id - 'X']) {
    return;
  }

  // Movement acceptable - do some moving
  switch(id) {
    case 'X': 
      pinStep = XSTEP;
      pinDir = XDIR;
      break;
    case 'Y':
      pinStep = YSTEP;
      pinDir = YDIR;
      break;
    case 'Z':
      pinStep = ZSTEP;
      pinDir = ZDIR;
      break;
    default:
      return;
  }

  // Recalc Position of Axis
  if(dir == 1) {
    motorPos[id - 'X'] -= steps;
    //Serial.print("Lowered Axis to ");
    //Serial.print(motorPos[id - 'X']);
  } else if(dir == 0) {
    motorPos[id - 'X'] += steps;
    //Serial.print("Increased Axis to ");
    //Serial.print(motorPos[id - 'X']);
  }  
  // Move it
  digitalWrite(pinDir, dir);
  while(steps > 0) {
    steps--;
    digitalWrite(pinStep, HIGH);
    delayMicroseconds(dly);
    digitalWrite(pinStep, LOW);
    delayMicroseconds(dly);
  }
}

void homeMotors(void) {
  homeMotor('X', 25);
  homeMotor('Y', 25);
  homeMotor('Z', 25);
}

uint32_t homeMotor(char id, uint16_t dly) {
  uint8_t pinStep, pinDir, pinEnd;
  uint16_t steps = 0;
  uint32_t stp = 0;
  switch(id) {
    case 'X': 
      pinStep = XSTEP;
      pinDir = XDIR;
      pinEnd = XMIN;
      motorPos[0] = 0;
      homed |= 0x01;
      break;
    case 'Y':
      pinStep = YSTEP;
      pinDir = YDIR;
      pinEnd = YMIN;
      motorPos[1] = 0;
      homed |= 0x02;
      break;
    case 'Z':
      pinStep = ZSTEP;
      pinDir = ZDIR;
      pinEnd = ZMIN;
      motorPos[2] = 0;
      homed |= 0x04;
      break;
    default:
      return 0;
  }
  enableMotor(id);
  digitalWrite(pinDir, 1);
  while(steps < X_STEPS_PER_MM*200 && digitalRead(pinEnd) == 1) {
    digitalWrite(pinStep, HIGH);
    delayMicroseconds(dly);
    digitalWrite(pinStep, LOW);
    delayMicroseconds(dly);
    stp++;
  }
  return stp;
}

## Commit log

2021-07-21 Working firmware, doing Scan over X-Axis.
2021-07-22 Added mechanical (printable) components.
    [X-Carriage.f3d, X-End.f3d, X-Idler.f3d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]
2021-08-22 Some bugfixes in motor control, first height-measurement featuring ice. <3
    [3d-plane-delta.py, Icing.ino, motors.cpp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]
2021-12-21 added old interfacing.
    [211006_Hoehenmessung.xlsx]
